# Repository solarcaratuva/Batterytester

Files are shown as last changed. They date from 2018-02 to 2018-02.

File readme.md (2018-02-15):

# UVA Solar Car Battery Assessment and Testing Device
## [Protected under Creative Commons Attribution ShareAlike CC BY-SA 4.0](https://creativecommons.org/licenses/by-sa/4.0/legalcode)

### This project was developed by the UVa Solar Car Team in order to test large numbers of lithium ion 18650 cells. By testing ESR and capacity one can be confident that each and every cell tested performs as expected and no cells have arrived DOA. Individually characterizing and 'binning' each cell allows us to arrange the cells in the final battery bank such that each module will have as close to identical capacity, reducing the chance of the modules SoC from drifting significantly over charge/discharge cycles.

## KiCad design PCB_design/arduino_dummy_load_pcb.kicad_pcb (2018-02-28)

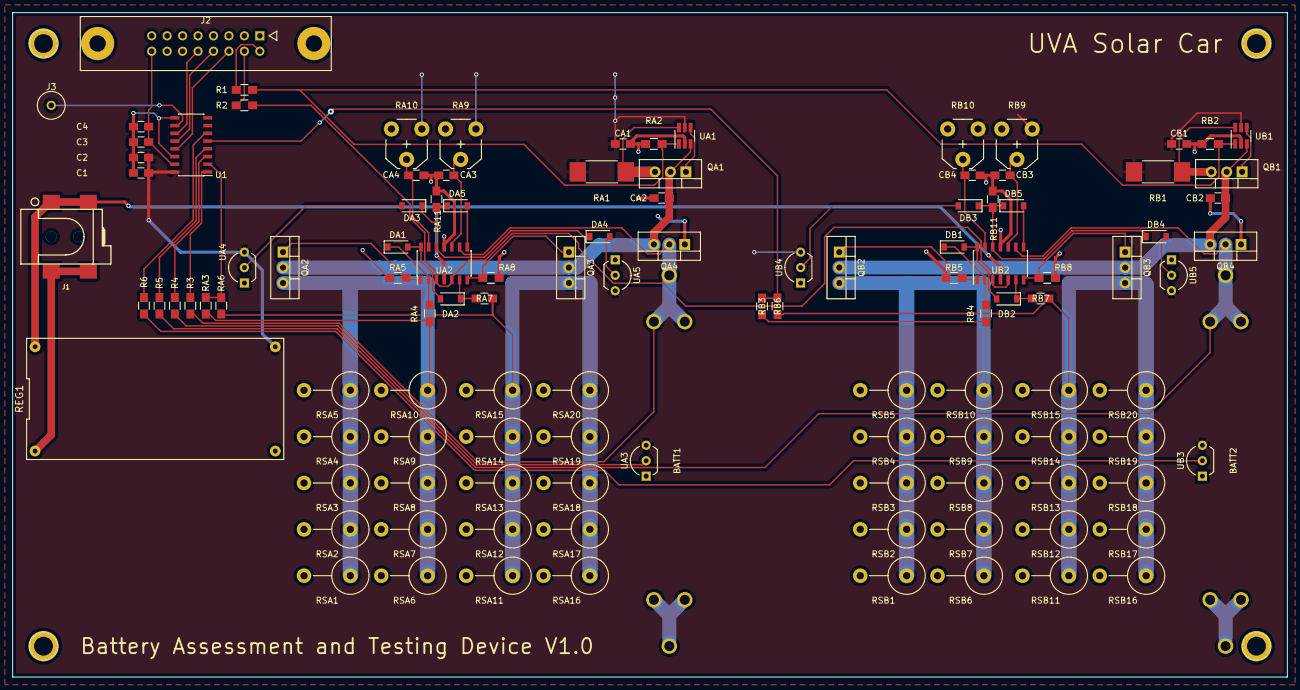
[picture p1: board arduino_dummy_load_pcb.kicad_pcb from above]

Board: 2 copper layers, 209.6 x 109.2 mm, 115 parts (0 on the bottom side), 55 nets.

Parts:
BATT1, BATT2: Battery_Cell; 18650
C1, C3: 10uF; C_0805_HandSoldering
C2, C4: 100nF; C_0805_HandSoldering
CA1, CA2: 10uF; C_0805_HandSoldering
CA3, CA4: 100nF; C_0805_HandSoldering
CB1, CB2: 10uF; C_0805_HandSoldering
CB3, CB4: 100nF; C_0805_HandSoldering
DA1, DA2, DA3, DA4, DA5: D; D_SOD-123
DB1, DB2, DB3, DB4, DB5: D; D_SOD-123
J1: Barrel_Jack; CUI-PJ-002AH-SMT_dc-barrel-jack
J2: Conn_02x08_Odd_Even; he10-16d
J3: Conn_01x01; 1pin
QA1, QA4: IPP45P03P4L-11; TO-220-3_Vertical
QA2, QA3: IRFZ44N; TO-220-3_Vertical
QB1, QB4: IPP45P03P4L-11; TO-220-3_Vertical
QB2, QB3: IRFZ44N; TO-220-3_Vertical
R1, R2, R3, R4, R5, R6: 47k; R_0805_HandSoldering
RA1: 50m; R_2512_HandSoldering
RA2, RA3, RA4, RA5, RA6, RA7, RA8: 47k; R_0805_HandSoldering
RA9, RA10: POT; Potentiometer_Trimmer_VishaySpectrol_Econtrim-Type36M
RA11: 10k; R_0805_HandSoldering
RB1: 50m; R_2512_HandSoldering
RB2, RB3, RB4, RB5, RB6, RB7, RB8: 47k; R_0805_HandSoldering
RB9, RB10: POT; Potentiometer_Trimmer_VishaySpectrol_Econtrim-Type36M
RB11: 10k; R_0805_HandSoldering
REG1: REG; LM2596_module
RSA1, RSA2, RSA3, RSA4, RSA5, RSA6, RSA7, RSA8, RSA9, RSA10, RSA11, RSA12, RSA13, RSA14, RSA15, RSA16, RSA17, RSA18, RSA19, RSA20: 10; R_Axial_DIN0617_L17.0mm_D6.0mm_P7.62mm_Vertical
RSB1, RSB2, RSB3, RSB4, RSB5, RSB6, RSB7, RSB8, RSB9, RSB10, RSB11, RSB12, RSB13, RSB14, RSB15, RSB16, RSB17, RSB18, RSB19, RSB20: 10; R_Axial_DIN0617_L17.0mm_D6.0mm_P7.62mm_Vertical
U1: MCP3208; SOIC-16_3.9x9.9mm_Pitch1.27mm
UA1: MCP73826; SOT-23-6_Handsoldering
UA2: LM324; SOIC-14_3.9x8.7mm_Pitch1.27mm
UA3, UA4, UA5: TMP36; TO-92_Inline_Wide
UB1: MCP73826; SOT-23-6_Handsoldering
UB2: LM324; SOIC-14_3.9x8.7mm_Pitch1.27mm
UB3, UB4, UB5: TMP36; TO-92_Inline_Wide

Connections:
+5V: C1.1, C2.1, CA1.1, CB1.1, RA1.1, RA9.1, RA10.1, RB1.1, RB9.1, RB10.1, REG1.4, U1.16, UA1.5, UA3.3, UA4.3, UA5.3, UB1.5, UB3.3, UB4.3, UB5.3
+9V: J1.1, REG1.1, UA2.4, UB2.4
/TEST-UNIT-A/STOP: DA1.2, DA2.2, UA2.14
/TEST-UNIT-B/STOP: DB1.2, DB2.2, UB2.14
BATT_A: BATT1.1, QA4.2, R3.2, UA2.9
BATT_B: BATT2.1, QB4.2, R5.2, UB2.9
CELL_TEMP_A: R4.2, UA3.2
CELL_TEMP_B: R6.2, UB3.2
CHARGE: R1.2, RA2.1, RB2.1, UA1.1, UB1.1
GND: BATT1.2, BATT2.2, C1.2, C2.2, C3.1, C4.1, CA1.2, CA2.2, CA3.2, CA4.2, CB1.2, CB2.2, CB3.2, CB4.2, J2.1, J2.3, J2.5, J2.7, J2.9, J2.11, J2.13, J2.15, QA4.1, QB4.1, RA2.2, RA5.1, RA8.1, RA9.3, RA10.3, RA11.1, RB2.2, RB5.1, RB8.1, RB9.3, RB10.3, RB11.1, REG1.3, RSA1.2, RSA2.2, RSA3.2, RSA4.2, RSA5.2, RSA6.2, RSA7.2, RSA8.2, RSA9.2, RSA10.2, RSA11.2, RSA12.2, RSA13.2, RSA14.2, RSA15.2, RSA16.2, RSA17.2, RSA18.2, RSA19.2, RSA20.2, RSB1.2, RSB2.2, RSB3.2, RSB4.2, RSB5.2, RSB6.2, RSB7.2, RSB8.2, RSB9.2, RSB10.2, RSB11.2, RSB12.2, RSB13.2, RSB14.2, RSB15.2, RSB16.2, RSB17.2, RSB18.2, RSB19.2, RSB20.2, U1.9, U1.14, UA1.2, UA2.11, UA3.1, UA4.1, UA5.1, UB1.2, UB2.11, UB3.1, UB4.1, UB5.1
I_OUT_A: RA3.1, RA6.1, U1.2
I_OUT_B: RB3.1, RB6.1, U1.5
I_SET: R2.2, UA2.3, UA2.5, UB2.3, UB2.5
unnamed: CA2.1, QA1.2, QA2.2, QA3.2, QA4.3, UA1.3
unnamed: CA3.1, RA9.2, UA2.10
unnamed: CA4.1, RA10.2, UA2.13
unnamed: CB2.1, QB1.2, QB2.2, QB3.2, QB4.3, UB1.3
unnamed: CB3.1, RB9.2, UB2.10
unnamed: CB4.1, RB10.2, UB2.13
unnamed: DA1.1, RA4.2, UA2.2
unnamed: DA2.1, RA7.2, UA2.6
unnamed: DA3.1, DA4.1, DA5.1, RA11.2, UA2.12
unnamed: DA3.2, UA4.2
unnamed: DA4.2, UA5.2
unnamed: DA5.2, UA2.8
unnamed: DB1.1, RB4.2, UB2.2
unnamed: DB2.1, RB7.2, UB2.6
unnamed: DB3.1, DB4.1, DB5.1, RB11.2, UB2.12
unnamed: DB3.2, UB4.2
unnamed: DB4.2, UB5.2
unnamed: DB5.2, UB2.8
unnamed: J1.2, J1.3, REG1.2
unnamed: J2.2, R1.1
unnamed: J2.4, R2.1
unnamed: J2.6, U1.13
unnamed: J2.8, U1.12
unnamed: J2.10, U1.11
unnamed: J3.1, U1.10
unnamed: QA1.1, UA1.4
unnamed: QA1.3, RA1.2, UA1.6
unnamed: QA2.1, RA5.2, UA2.1
unnamed: QA2.3, RA3.2, RA4.1, RSA1.1, RSA2.1, RSA3.1, RSA4.1, RSA5.1, RSA6.1, RSA7.1, RSA8.1, RSA9.1, RSA10.1
unnamed: QA3.1, RA8.2, UA2.7
unnamed: QA3.3, RA6.2, RA7.1, RSA11.1, RSA12.1, RSA13.1, RSA14.1, RSA15.1, RSA16.1, RSA17.1, RSA18.1, RSA19.1, RSA20.1
unnamed: QB1.1, UB1.4
unnamed: QB1.3, RB1.2, UB1.6
unnamed: QB2.1, RB5.2, UB2.1
unnamed: QB2.3, RB3.2, RB4.1, RSB1.1, RSB2.1, RSB3.1, RSB4.1, RSB5.1, RSB6.1, RSB7.1, RSB8.1, RSB9.1, RSB10.1
unnamed: QB3.1, RB8.2, UB2.7
unnamed: QB3.3, RB6.2, RB7.1, RSB11.1, RSB12.1, RSB13.1, RSB14.1, RSB15.1, RSB16.1, RSB17.1, RSB18.1, RSB19.1, RSB20.1
unnamed: R3.1, U1.1
unnamed: R4.1, U1.3
unnamed: R5.1, U1.4
unnamed: R6.1, U1.6
VREF: C3.2, C4.2, J2.16, U1.15

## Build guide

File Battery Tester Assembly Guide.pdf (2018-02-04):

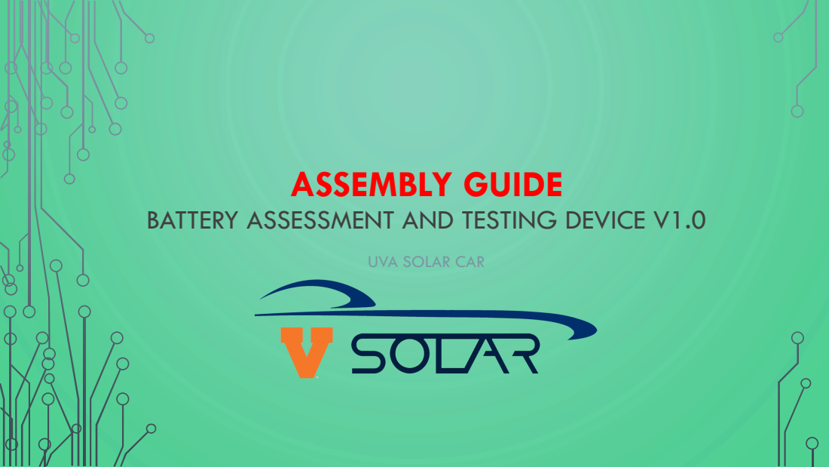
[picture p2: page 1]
ASSEMBLY GUIDE

BATTERY ASSESSMENT AND TESTING DEVICE V1.0

UVA SOLAR CAR

# WHAT NOT TO POPULATE

## - UA1, UA4, UA5 - DA1 – DA5 - CA1 – CA4 - RA1, RA2, RA9, RA10

- QA1

## - UB1, UB4, UB5 - DB1 – DB5 - CB1 – CB4 - RB1, RB2, RB9, RB10

- QB1 Why?

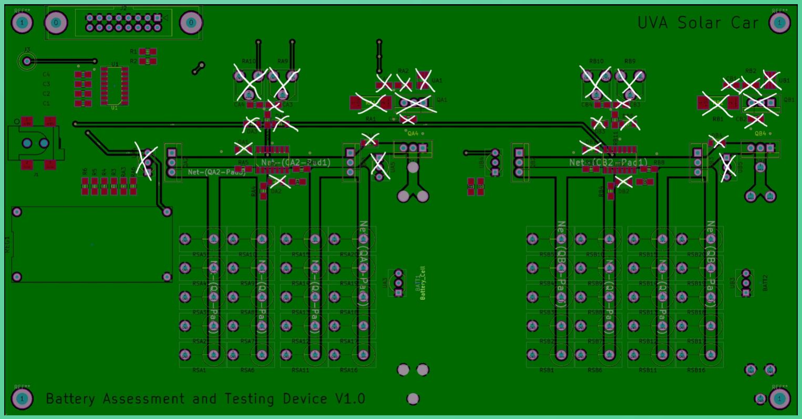
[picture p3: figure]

These slots were designated for hardware over-temperature and over-voltage protection. They were expensive to populate, and the same protection can be done through software. Other crossed off slots are for battery charging, which will be implemented externally.

# SOLDERING COMPONENTS: 12 STEPS

## 1. Through hole resistors

## 2. Surface mount resistors

## 3. Capacitors

## 4. Op Amps

## 5. Analog to Digital Converter (ADC)

## 6. Wire Housing

## 7. Chip Select Pin

## 8. Buck Converter

## 9. Battery Contacts

## 10. Temperature Sensors

## 11. MOSFETS

## 12. DC Power Jack

# STEP 1: THROUGH HOLE RESISTORS

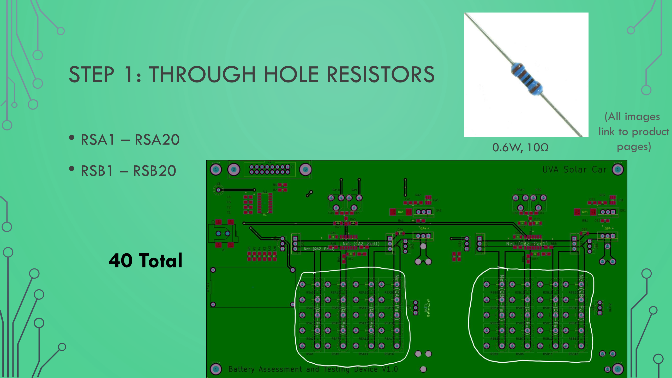
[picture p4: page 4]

## - RSA1 – RSA20

## - RSB1 – RSB20

0.6W, 10Ω

(All images
link to product
pages)

# 40 Total

# STEP 2: SURFACE MOUNT RESISTORS

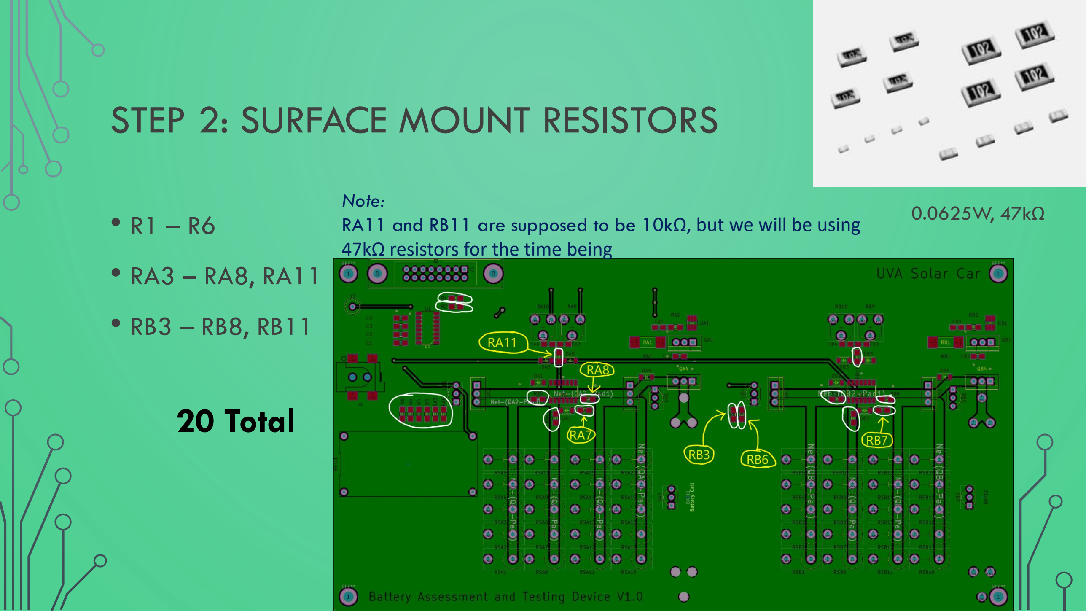
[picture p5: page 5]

- R1 – R6

## - RA3 – RA8, RA11

## - RB3 – RB8, RB11

0.0625W, 47kΩ

# 20 Total

Note:
RA11 and RB11 are supposed to be 10kΩ, but we will be using 47kΩ resistors for the time being

# STEP 3A: SURFACE MOUNT CAPACITORS

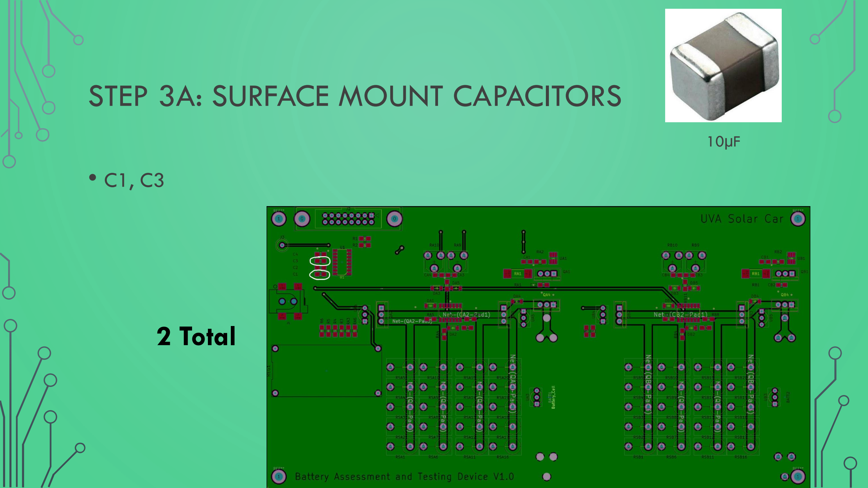
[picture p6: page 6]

- C1, C3

10µF

# 2 Total

# STEP 3B: SURFACE MOUNT CAPACITORS

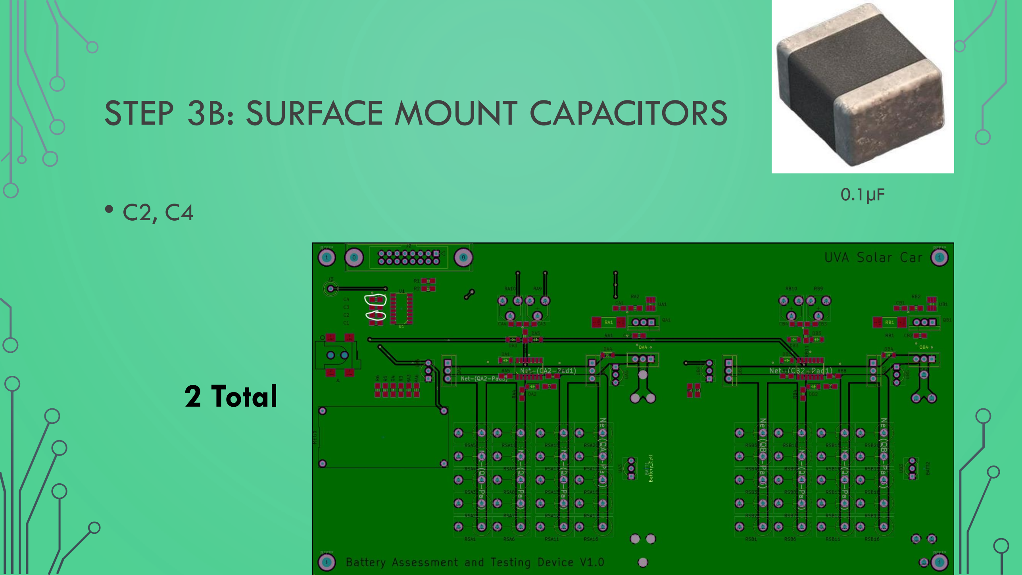
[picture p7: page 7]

- C2, C4

0.1µF

# 2 Total

# STEP 4: OP AMPS

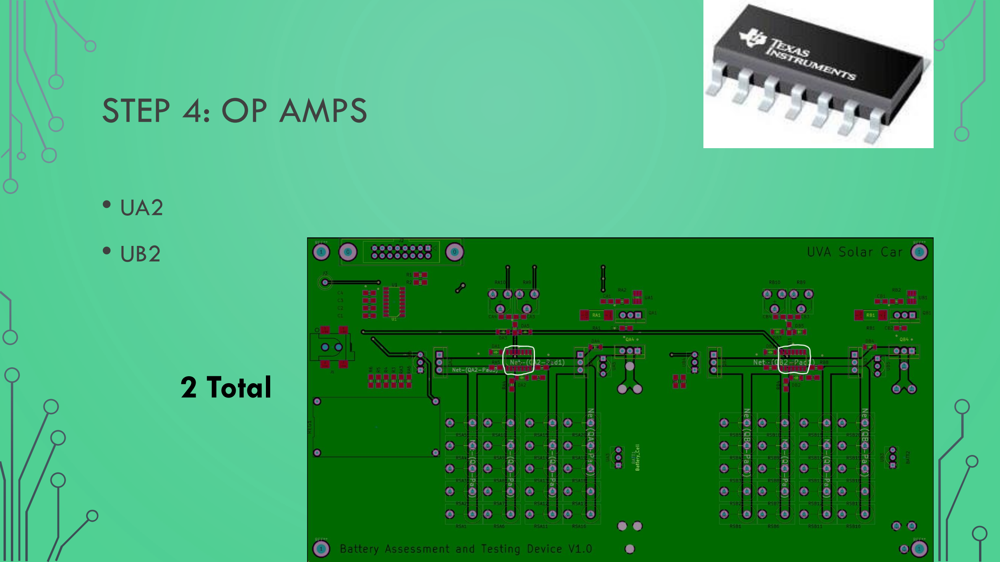
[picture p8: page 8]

- UA2
- UB2

# 2 Total

# STEP 5: ANALOG TO DIGITAL CONVERTER (ADC)

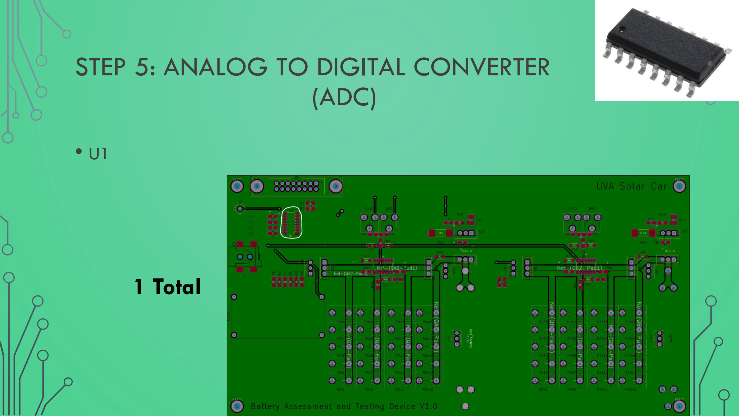
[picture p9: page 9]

- U1

# 1 Total

# STEP 6: WIRE HOUSING

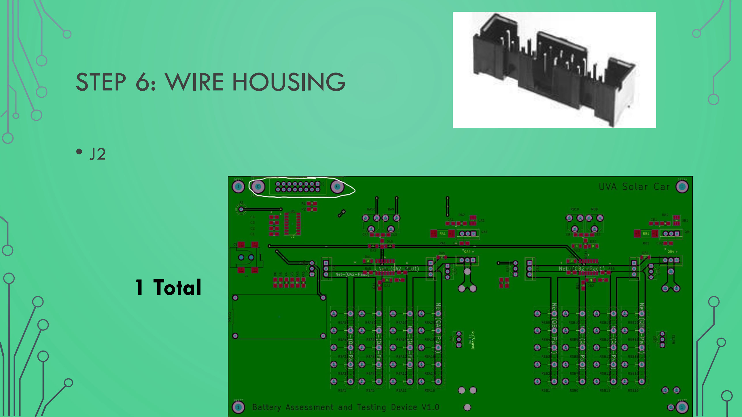
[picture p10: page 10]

- J2

# 1 Total

# STEP 7: CHIP SELECT PIN

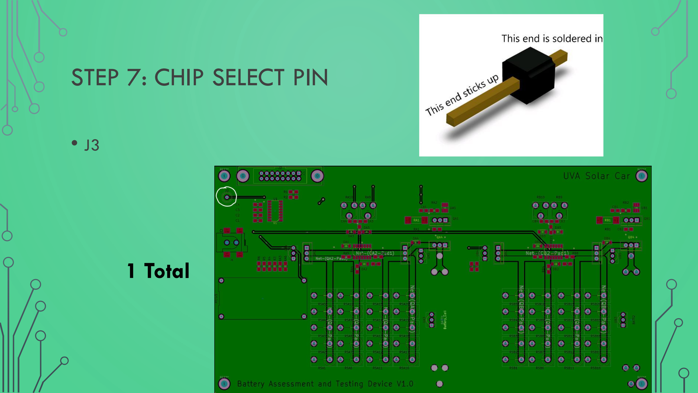
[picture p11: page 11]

- J3

# 1 Total

# STEP 8A: BUCK CONVERTER PIN HEADERS

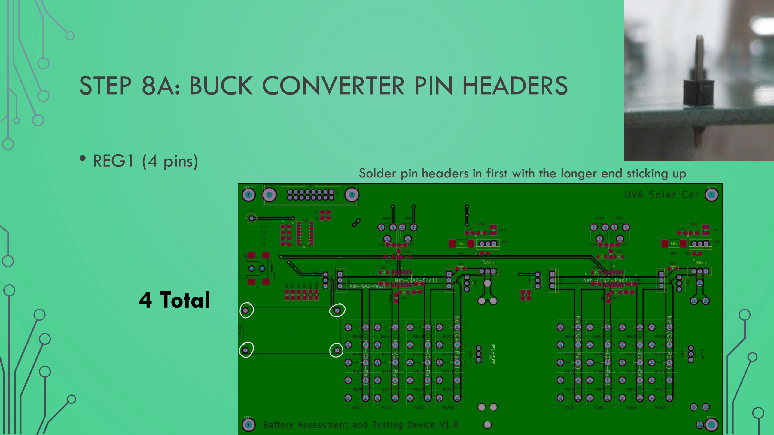
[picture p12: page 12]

## - REG1 (4 pins)

# 4 Total

Solder pin headers in first with the longer end sticking up

# STEP 8B: BUCK CONVERTER

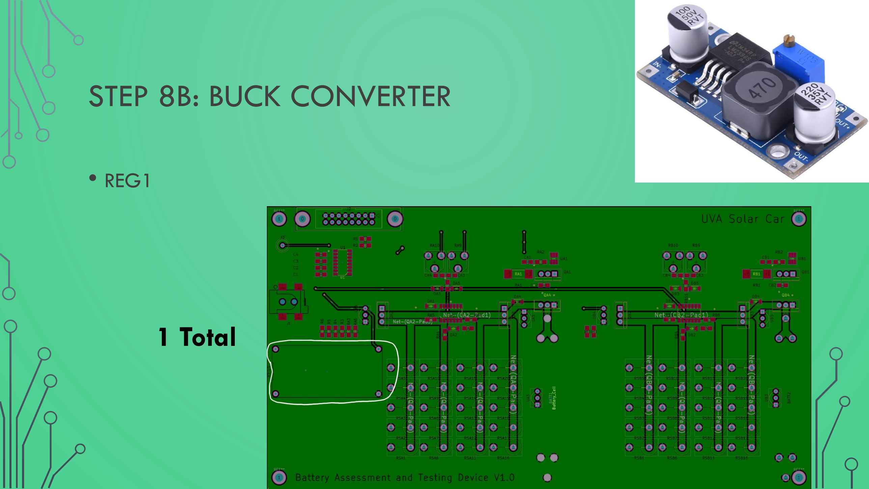
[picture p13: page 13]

## - REG1

# 1 Total

# STEP 9: BATTERY CONTACTS

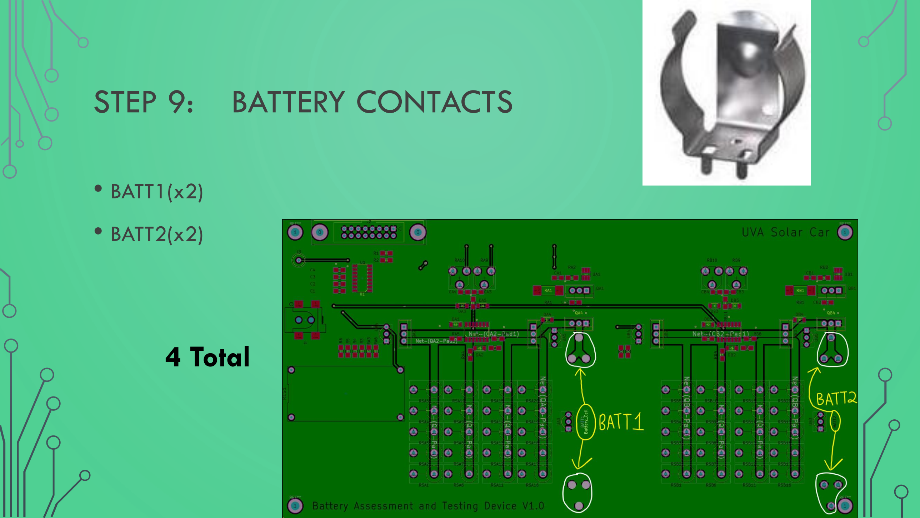
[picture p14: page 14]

## - BATT1(x2)

## - BATT2(x2)

# 4 Total

# STEP 10: TEMPERATURE SENSORS

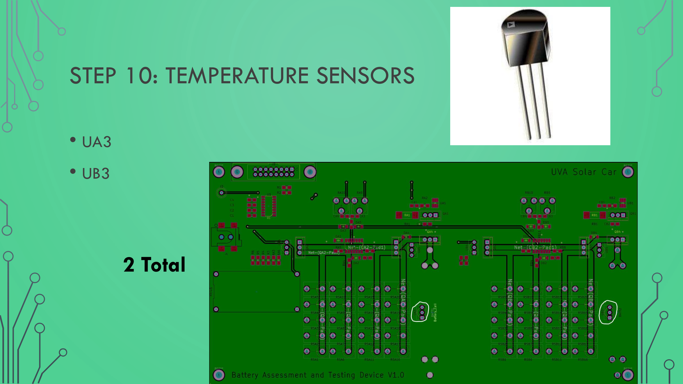
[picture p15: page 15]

- UA3
- UB3

# 2 Total

# STEP 11A: MOSFETS

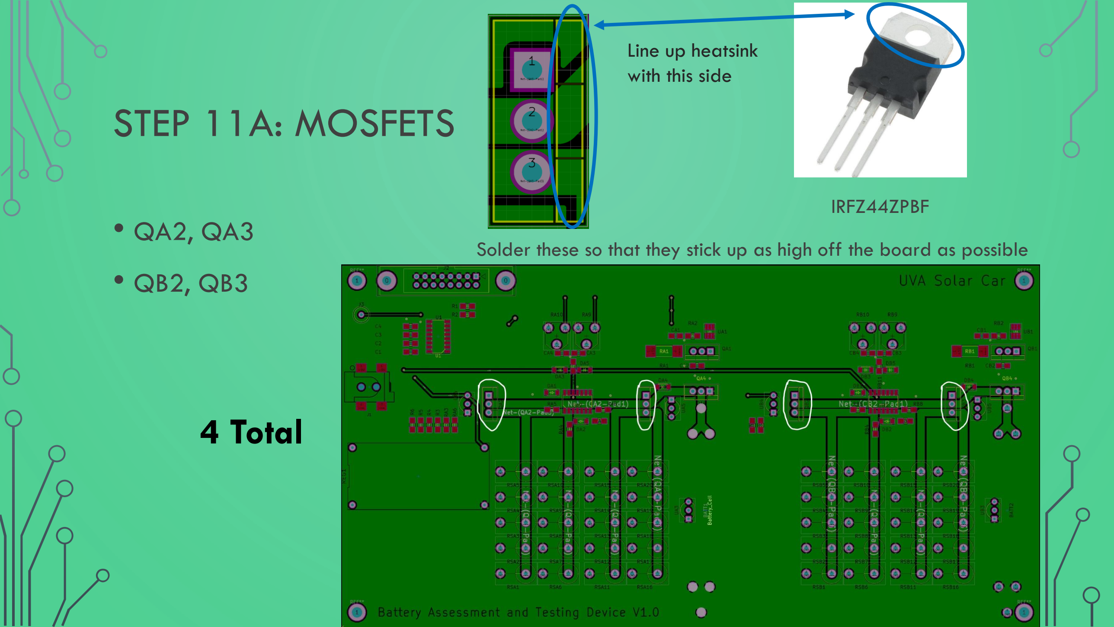
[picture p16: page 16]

## - QA2, QA3

## - QB2, QB3

# 4 Total

IRFZ44ZPBF

Line up heatsink
with this side

Solder these so that they stick up as high off the board as possible

# STEP 11B: MOSFETS

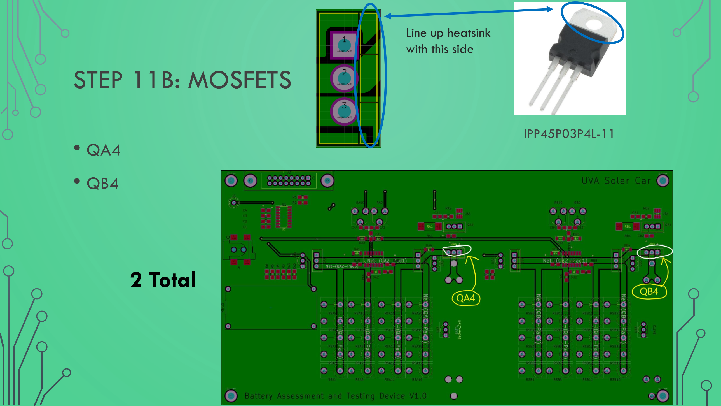
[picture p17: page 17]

- QA4
- QB4

# 2 Total

IPP45P03P4L-11

Line up heatsink
with this side

# STEP 12: DC POWER JACK

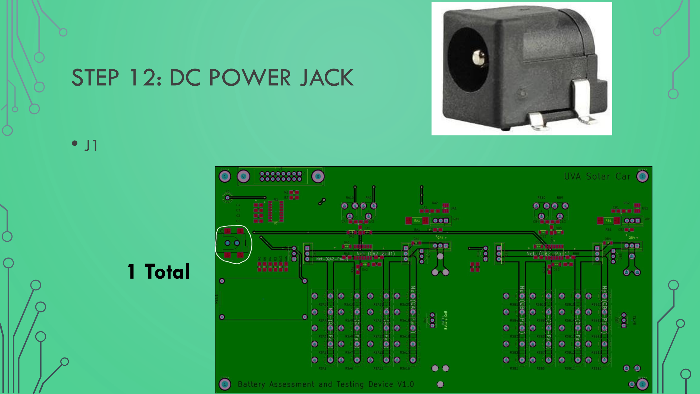
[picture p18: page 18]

- J1

# 1 Total

# FINISHING TOUCH

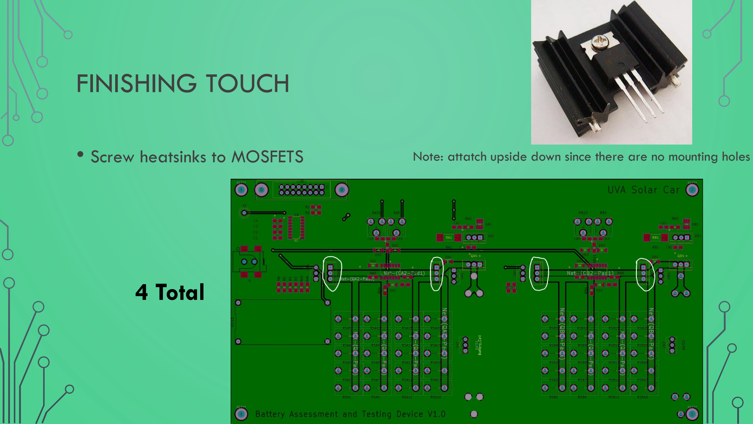
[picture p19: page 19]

## - Screw heatsinks to MOSFETS

# 4 Total

Note: attatch upside down since there are no mounting holes

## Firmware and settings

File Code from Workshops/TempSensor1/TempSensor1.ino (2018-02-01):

#include<Wire.h>
#include<LiquidCrystal_I2C.h>
#include <MCP3208.h>
#include <SPI.h>

MCP3208 adc(10);

LiquidCrystal_I2C lcd(0x27, 2, 1, 0, 4, 5, 6, 7, 3, POSITIVE);
int tempPin1_1 = 0;             // Package 1: Temp reading pin
int tempPin1_2 = 1;             // Package 1: Temp reading pin
int tempPin1_3 = 2;             // Package 1: Temp reading pin for battery
int volPin1    = 3;             // Package 1: Voltage pin for battery

int tempPin2_1 = 4;             // Package 2: Temp reading pin
int tempPin2_2 = 5;             // Package 2: Temp reading pin
int tempPin2_3 = 6;             // Package 2: Temp reading pin for battery
int volPin2    = 7;             // Package 2: Voltage pin for battery

int MIN_TEMP = -20;           // Min temperature limit
int MAX_TEMP = 50;            // Max temperature limit
int VOL      = 3.9;           // Voltage upperlimit


void setup() {
  lcd.begin(16,2);
  lcd.clear();
  Serial.begin(9600);
}

double readVoltage(int pin){
  double reading = adc.analogRead(pin);
  double Voltage = map(reading, 0, 4095, 0, 5000)/1000.0;
  return Voltage;
}

void loop() {
  double Voltage1_1 = readVoltage(tempPin1_1);
  double Voltage1_2 = readVoltage(tempPin1_2);
  double Voltage1_3 = readVoltage(tempPin1_3);
  double Voltage1_4 = readVoltage(volPin1);
  double Voltage2_1 = readVoltage(tempPin2_1);
  double Voltage2_2 = readVoltage(tempPin2_2);
  double Voltage2_3 = readVoltage(tempPin2_3);
  double Voltage2_4 = readVoltage(volPin2);
  
  double tempC1_1 = 100.0 * (Voltage1_1) - 50.0;
  double tempC1_2 = 100.0 * (Voltage1_2) - 50.0;
  double tempC1_3 = 100.0 * (Voltage1_3) - 50.0;
  double tempC2_1 = 100.0 * (Voltage2_1) - 50.0;
  double tempC2_2 = 100.0 * (Voltage2_2) - 50.0;
  double tempC2_3 = 100.0 * (Voltage2_3) - 50.0;
  
  
  if(tempC1_1>MAX_TEMP||tempC1_2>MAX_TEMP||tempC1_3>MAX_TEMP||tempC2_1>MAX_TEMP||tempC2_2>MAX_TEMP||tempC2_3>MAX_TEMP){
    Serial.println("The temperature passes the upper limit.");
  }
  if(tempC1_1<MIN_TEMP||tempC1_2<MIN_TEMP||tempC1_3<MIN_TEMP||tempC2_1<MIN_TEMP||tempC2_2<MIN_TEMP||tempC2_3<MIN_TEMP){
    Serial.println("The temperature passes the lower limit.");
  }
  if(Voltage1_4>3.9||Voltage2_4>3.9){
    Serial.println("The Battery passes the nominal limit");
  }
  
  //lcd.print(tempC1); lcd.print(" Degree Celcius");
  delay(1000);
}
//Serial.print("Volatge for Package 1 is ");Serial.print(Voltage1);
//Serial.print("Volatge for Package 2 is ");Serial.print(Voltage2);
/**double tempF1 = (tempC1 * 9.0 / 5.0) + 32.0;
  double tempF2 = (tempC2 * 9.0 / 5.0) + 32.0;
  double tempF3 = (tempC2 * 9.0 / 5.0) + 32.0;**/

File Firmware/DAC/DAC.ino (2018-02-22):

/*
 * Library acquired from https://github.com/MajenkoLibraries/MCPDAC
 */
#include <SPI.h>
#include "MCPDAC.h"

/*
 * Pin 2 = CSPin = 10
 * Pin 3 = SCK = 13
 * Pin4 = SDI = 11
 * Pin 8 = VoutA
 * Pin 6 = VoutB
 */

void setup() {
  // put your setup code here, to run once:
  MCPDAC.begin();

  MCPDAC.setGain(CHANNEL_A,GAIN_HIGH);

  // Do not shut down channel A, but shut down channel B.
  MCPDAC.shutdown(CHANNEL_A,false);
  //MCPDAC.shutdown(CHANNEL_B,true);
}

void loop() {
  // NOTE: Discharge Current = 2 * DAC Output voltage
  unsigned int mv = 1000;
  MCPDAC.setVoltage(CHANNEL_A, mv&0x0FFF);
}

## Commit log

2017-10-24 Initial commit of BatteryTester code. It's just messing with some registers to setup fast PWM. Lots of work ahead of us!
2017-10-25 Initial circuit design (concept)x
    [arduino_dummy_load_pcb.kicad_pcb, arduino_dummy_load_pcb.sch]
2017-10-25 Created protection circuitry for channel B, added decoupling capacitor for 78L05, rearranged a few elements
    [arduino_dummy_load_pcb.sch]
2017-10-26 Added lithium ion charging circuitry and labeled all components
    [arduino_dummy_load_pcb.sch]
2017-10-26 Fixed connector. This should be the first version of the schematic which is fully functional, but completly untested.
    [arduino_dummy_load_pcb.sch]
2017-10-26 Fixed a few "bugs" (forgot to do DRC check!) and also added the batteries!
    [arduino_dummy_load_pcb.sch]
2017-10-26 Gave components footprints and started PCB layout
    [_saved_arduino_dummy_load_pcb.sch, arduino_dummy_load_pcb.sch]
2017-10-29 Latest commit
    [_saved_arduino_dummy_load_pcb.sch, arduino_dummy_load_pcb.kicad_pcb, arduino_dummy_load_pcb.sch]
2017-11-04 Fixed a few mistakes, Implemented reverse polarity protection w/ MOSFETs.
    [arduino_dummy_load_pcb.sch]
2017-11-09 refactored the redundant battery testing units into hierarchical blocks. TODO: still need to add voltage reference component and create custom PCB footprint for the battery.
    [DummyLoad.sch, arduino_dummy_load_pcb.sch]
2017-11-18 KiCad routing for the win!
    [DummyLoad.sch, _saved_arduino_dummy_load_pcb.sch, arduino_dummy_load_pcb.kicad_pcb]
2017-11-18 Add files via upload
    RTC Clock and SD Card Combined Code. Currently reads in RTC hour/minute/second and writes it to a unique filename. The unique filename consists of: battery number (pin 4 or 5), batch number (batch 1 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
2017-11-22 changes have been made. Lives have been improved. I'm not the poetic type but this just worked. :)
    [DummyLoad.sch, _saved_arduino_dummy_load_pcb.sch, arduino_dummy_load_pcb.sch]
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2017-11-25 nearly finished PCB layout and routing
    [DummyLoad.sch, _saved_arduino_dummy_load_pcb.sch, arduino_dummy_load_pcb.kicad_pcb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]
2017-11-26 Finalized/finished PCB layout. Phew! Version 0.00. Hopefully it works (fingers crossed)!
    [DummyLoad.sch, _saved_arduino_dummy_load_pcb.sch, arduino_dummy_load_pcb.kicad_pcb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]
2017-11-27 adding gerber files
    [arduino_dummy_load_pcb-B.Cu.gbr, arduino_dummy_load_pcb-B.Mask.gbr, arduino_dummy_load_pcb-Edge.Cuts.gbr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]
2017-11-27 added drill file
    [arduino_dummy_load_pcb-Edge.Cuts.gbr, arduino_dummy_load_pcb.drl]
2017-12-03 Resized vias in order to reduce potential showstoppers in DFM Checks
    [_saved_arduino_dummy_load_pcb.sch, arduino_dummy_load_pcb.kicad_pcb]
2017-12-04 PCB with only one DFM error
    [arduino_dummy_load_pcb.kicad_pcb]
2017-12-04 Cleaned up export folder
    [arduino_dummy_load_pcb-B.Cu.gbr, arduino_dummy_load_pcb-B.Mask.gbr, arduino_dummy_load_pcb-F.Cu.gbr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]
2017-12-05 Fixed apparent Kicad DRC errors (VCC floodfill in some areas was isolated from VCC.) and one via that was too close to a track, and deleted some garbage traces
    [arduino_dummy_load_pcb.kicad_pcb]
2017-12-05 added readme (needs lots of work), basically final PCB
    [DummyLoad.sch, arduino_dummy_load_pcb.kicad_pcb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]
2017-12-05 Added Silkscreen Labels :)
    [arduino_dummy_load_pcb.kicad_pcb]
2017-12-05 Moved components in the top left away from the corner...still need to adjust copper pours
    [arduino_dummy_load_pcb.kicad_pcb]
2017-12-05 Updated Gerber exports to V1.01
    [arduino_dummy_load_pcb-B.Cu.gbr, arduino_dummy_load_pcb-B.Mask.gbr, arduino_dummy_load_pcb-F.Cu.gbr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]
2017-12-05 Removed text on copper Bottom
    [arduino_dummy_load_pcb.kicad_pcb]
2017-12-05 Re-routed traces that were broken by moving components away from corner
    [arduino_dummy_load_pcb.kicad_pcb]
2017-12-05 Updated to Gerber Export V1.02
    [arduino_dummy_load_pcb.kicad_pcb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]
2017-12-05 Added mounting holes & rerouted accordingly
    [arduino_dummy_load_pcb.kicad_pcb]
2017-12-05 Fixed a couple of typos
2017-12-06 Added Gerber Export V1.03
    [arduino_dummy_load_pcb-B.Cu.gbr, arduino_dummy_load_pcb-B.Mask.gbr, arduino_dummy_load_pcb-F.Cu.gbr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]
2017-12-06 Fixed the CS pin
    [arduino_dummy_load_pcb.kicad_pcb]
2017-12-06 Updated to Gerber Export V1.04
    [arduino_dummy_load_pcb-B.Cu.gbr, arduino_dummy_load_pcb-B.Mask.gbr, arduino_dummy_load_pcb-F.Cu.gbr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]
2017-12-19 adding to unstable branch
    [arduino_dummy_load_pcb.kicad_pcb, arduino_dummy_load_pcb.sch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]
2017-12-19 fixed all of @malcolms problems :)
    [arduino_dummy_load_pcb.kicad_pcb]
2017-12-19 Updated to Gerber Export v1.05
    [arduino_dummy_load_pcb-B.Cu.gbr, arduino_dummy_load_pcb-B.Mask.gbr, arduino_dummy_load_pcb-B.SilkS.gbr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]
2017-12-19 Added Gerber Export v1.05
    [Board Outline (edge cuts).gbr, Bottom Soldermask.gbr, Copper Bottom.gbr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]
2018-01-18 Moved Arduino Files into folders so that they can be easily opened
2018-01-18 Fixing directories for Arduino files
    [RTC_SD_Combined.ino, TempSensor1.ino]
2018-02-01 Cleaned up data processing files
    [DATA.CSV]
2018-02-01 Moved 'Data Logging' out of firmware and renamed it 'Data Processing'
    [DATA.CSV]
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2018-02-01 Updated broken filename in Capacities to Battery Pack script
2018-02-01 Added files for meeting
    [DATA.CSV]
2018-02-01 Added Jame's temperature reading software
    [TemperatureReading.ino]
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2018-02-03 adding file adders
    [data_processing_test.csv]
2018-02-03 file readers
    [data_processing_test.csv]
2018-02-03 Added Battery Identification
    Created battery identification, batteries will be numbered 1 to 416, and this can be accessed through the 'pack' matrix which contains the ordering of the batteries, and the 'pack2' matrix which cont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
2018-02-03 Updated Battery Indices
    Battery Indices are now correlated to A1-A36,B1-B36...M1-M36 in a matrix called indexCells. The actual battery values are in a matrix called pack.
2018-02-04 Updated calculations in temperature sensor (Thanks James)
    [TemperatureReading.ino]
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2018-02-16 Updated discharge library (Thanks James & Josie)
    [Discharger.cpp]
2018-02-16 Data_Processing & Capacities_Battery ARE DONE!!!!
    THEY ARE ALL DONE!!!!! Data_Processing should be in the same folder as BatchA,BatchB,....BatchN.csv . Then, run that program. Then, go to Capacities_Battery and run that. Yay, you have finished the t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
    [batchA.csv, batchB.csv]
2018-02-19 Added Configure_RTC (s/o to Adam) and fixed typo in TempReading
    [TemperatureReading.ino]
2018-02-22 Added RTC Library and updated #define statement so that the library doesn't need to be manually downloaded and added
    [BatteryTester.ino]
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2018-02-28 cleaned stuff up, implemented Discharger class the way it was supposed to be implemented, and fixed problems with mcp3208. Discharger still needs some work, especally in order to use I2C later. I wou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
    [arduino_dummy_load_pcb.kicad_pcb]
2018-03-08 Fixed bug with attachInterrupt. (I had to wrap the variable increment inside of a lambda since funny things happen if you don't.
    [CSVWriter.cpp, newBatteryTester.ino]
2018-03-08 BatteryCell library is not useful library since it's functionallity can be replaced entirely with a simple array. Rm'ed. Added DAC functionallity to newBatteryTester and verified functionallity. Once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
    TOD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
    [CSVWriter.cpp, newBatteryTester.ino]
2018-03-25 fixed bugs associated with switch found bugs with discharger.h possible bugs with decoder.h
    | |
    \ \___/ /
    \ / \ /
    ----| |-----
    / \___/ \
    / \
    | |
    [newBatteryTester.ino]
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2018-04-06 Fixed bugs with decoder.h Refactored NewBatteryTester folder into BatteryTester. (there is no reason to keep it anymore. It is obsolete. (Keep in mind, if anything useful was in it, it should still e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
    [BatteryTester.ino, CSVWriter.cpp, Discharger.cpp]
2018-04-13 fixed tempurature reading fixed discharger naming convention fixed name for project
    [BatteryTester.ino]
2018-04-19 fixed a few bugs, found another that needs to be fixed: when overcurrent on a cell is detected, it needs to shut off all cells and go to the "off" state rather than read the next battery voltage, see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
    [BatteryTester.ino]
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
